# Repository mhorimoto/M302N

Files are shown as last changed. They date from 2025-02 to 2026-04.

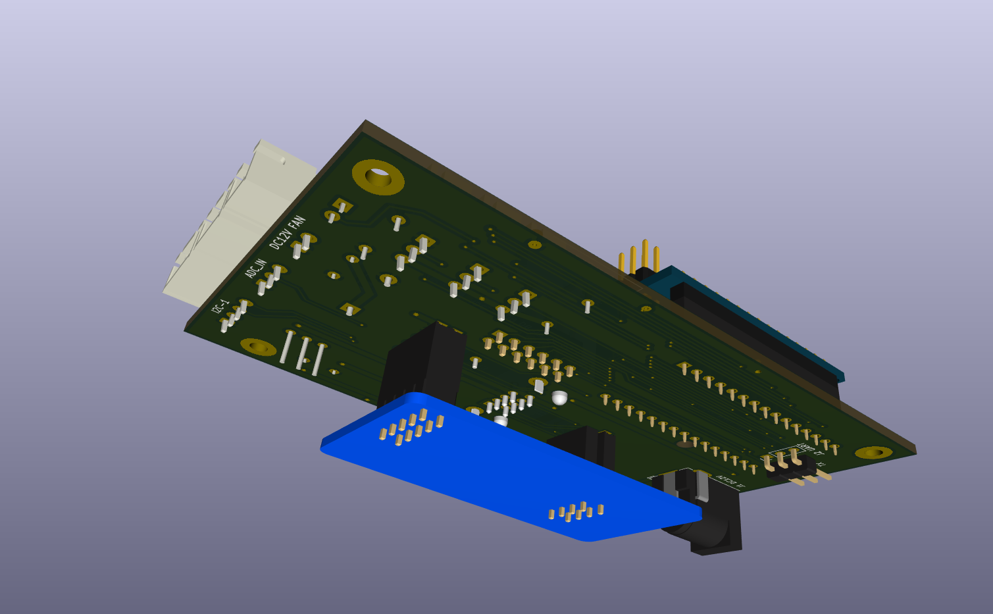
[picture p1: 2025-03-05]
M302N-3D-02.png

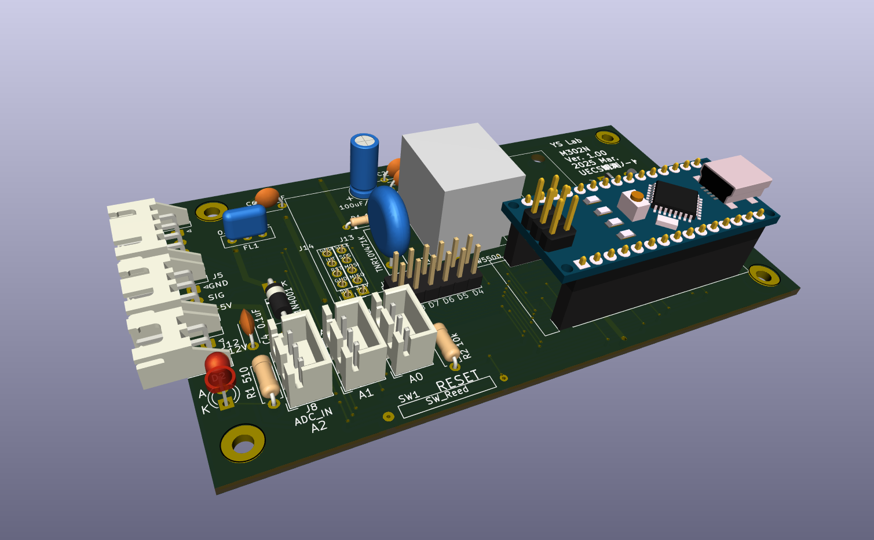
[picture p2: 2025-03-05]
M302N-3D-01.png

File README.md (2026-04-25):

# M302N3

New hardware that improves on the M302K to make it smaller, more dedicated and no-code.

M302Kを改良して小型化、専用化とノーコード化を目指した新しいハードウェア  
M302N2を使用して、
* 気温湿度
* CO2
* 光量子 or 日射量
* 土中水分

を1台で観測可能とする

ここまでが M302N2-ULTRA これからが、M302N3 本当のPoEを採用する

## Main specifications

## パーツリスト

N3のための新規パーツ（現在検討中）

+ RJ-45モジュール Pulse YAGEO J00-0065NL
+ PoE モジュール Silvertel Ag9912-MT 12V出力の工業規格

## 主諸元
+ I2CとADC入力を備えたUECS測定ノード機
+ I/Oは5V
+ 電源電圧はDC12V/1A(Max)
+ M800系のPoEは使えなくなる

## Revision List

### 1.00 初版 (2025/03/09)
### 2.00 
* J1の結線ミスを修正 (Done 2025/05/12)
* J2のUARTはSoftwareSerial対応にして、D0,D1を空けておき、D8,D9をRX,TXに割り当てる。5V Vccの追加。 (Done 2025/05/12)
* J3の対応ピンを変更する。Hardware InterruptのD2,D3を入力端子として扱えるように。D2,3,4,5,6,7 (Done 2025/05/12)
* LED-D2はA0に割り当てる
* J9,J10 の削除 (Done 2025/05/12)
* J11 止め穴を0.1mm大きくする
* SW1はXH-B2Bに変更 (Done 2025/05/12)
* J1へCPUから5Vが逆流しないように1S4を追加 (Done 2025/05/12)
### 3.00

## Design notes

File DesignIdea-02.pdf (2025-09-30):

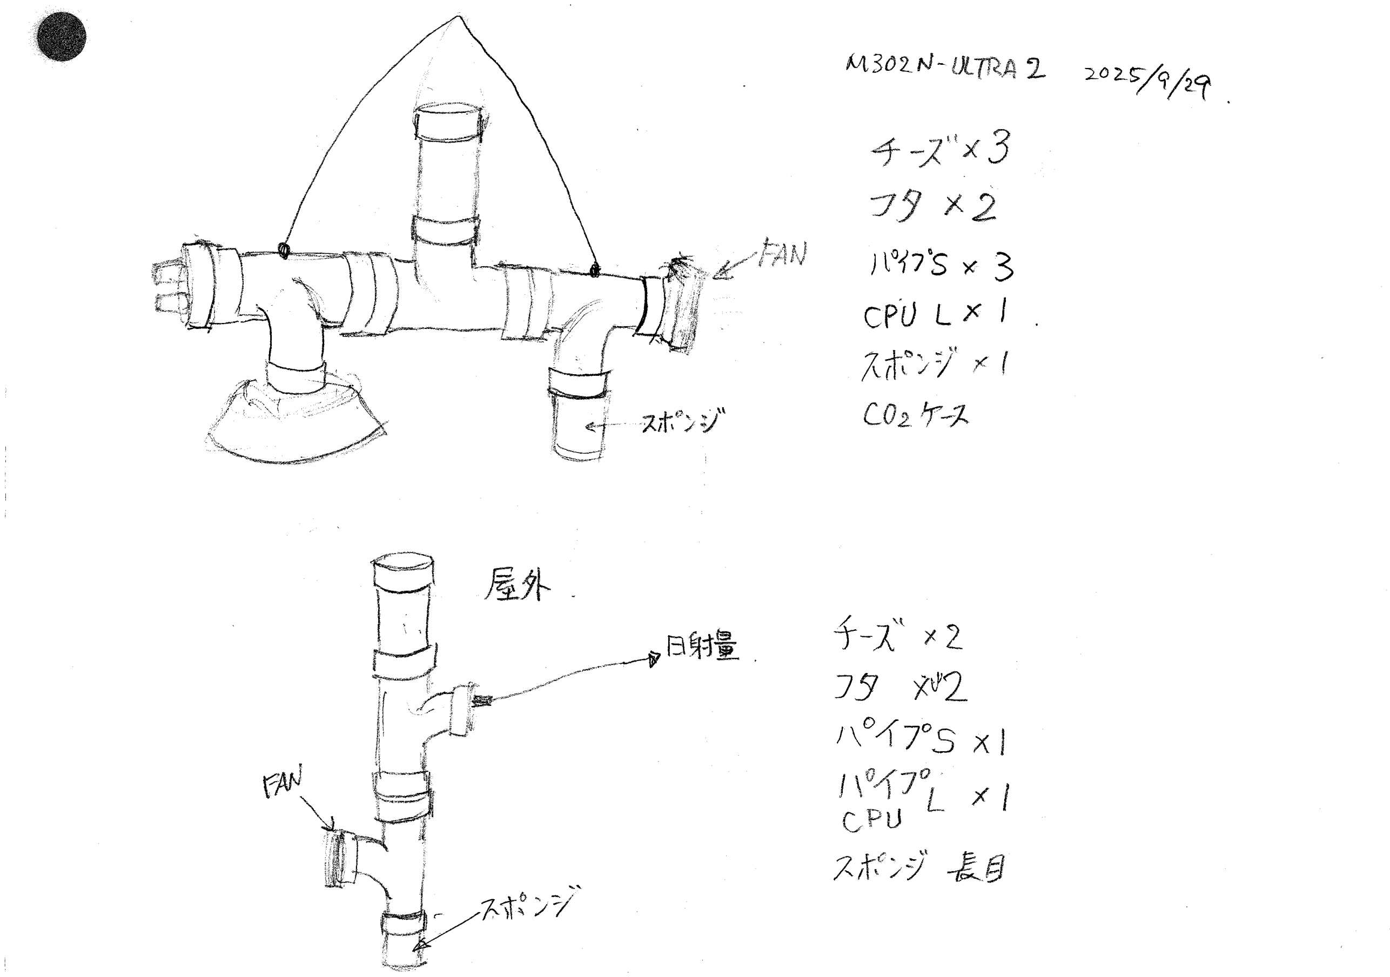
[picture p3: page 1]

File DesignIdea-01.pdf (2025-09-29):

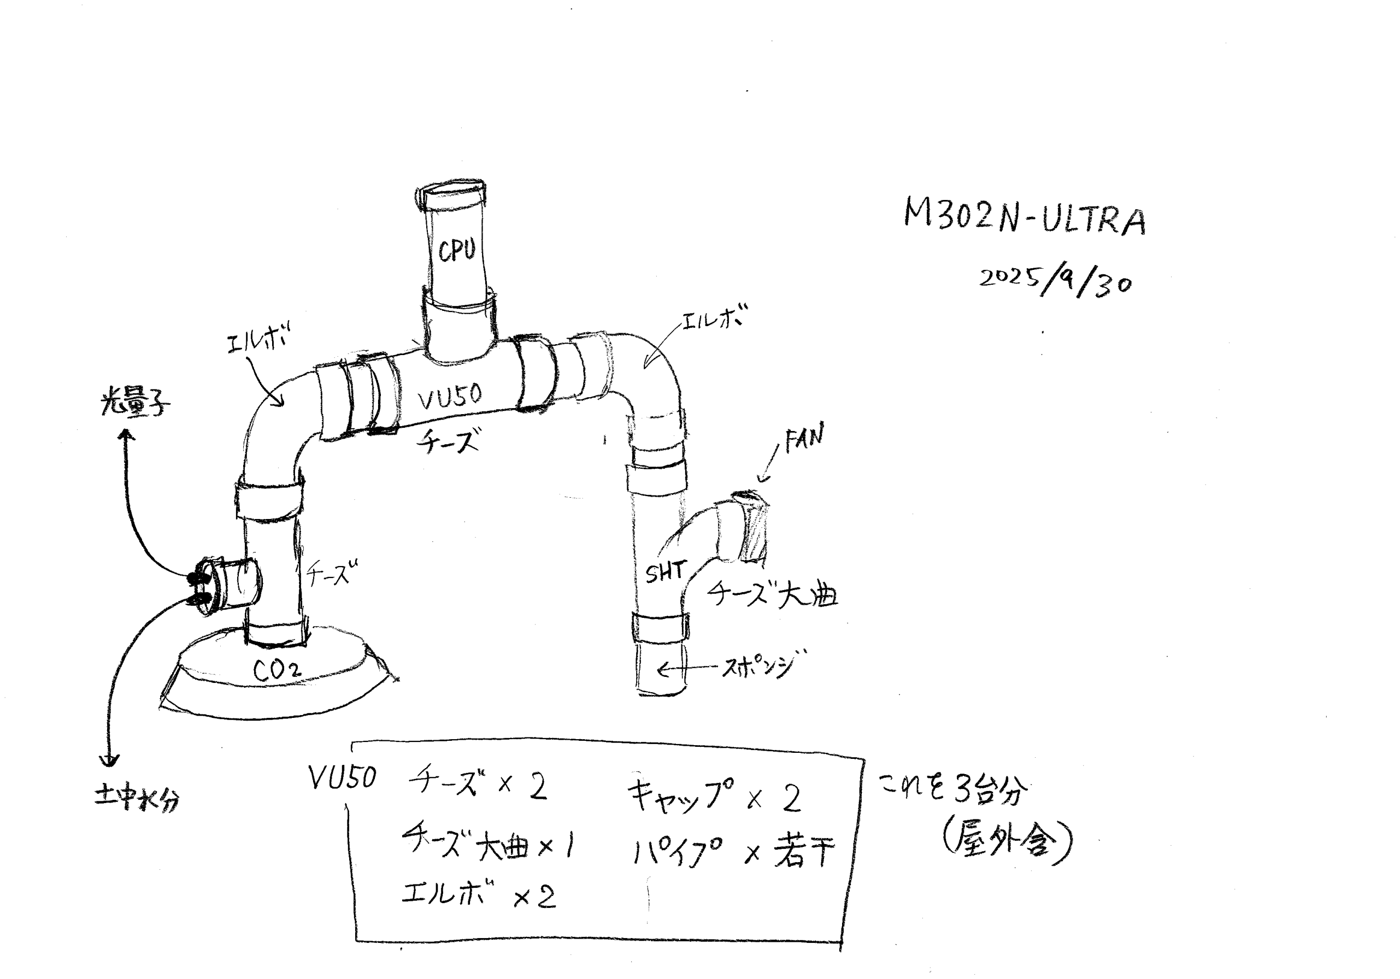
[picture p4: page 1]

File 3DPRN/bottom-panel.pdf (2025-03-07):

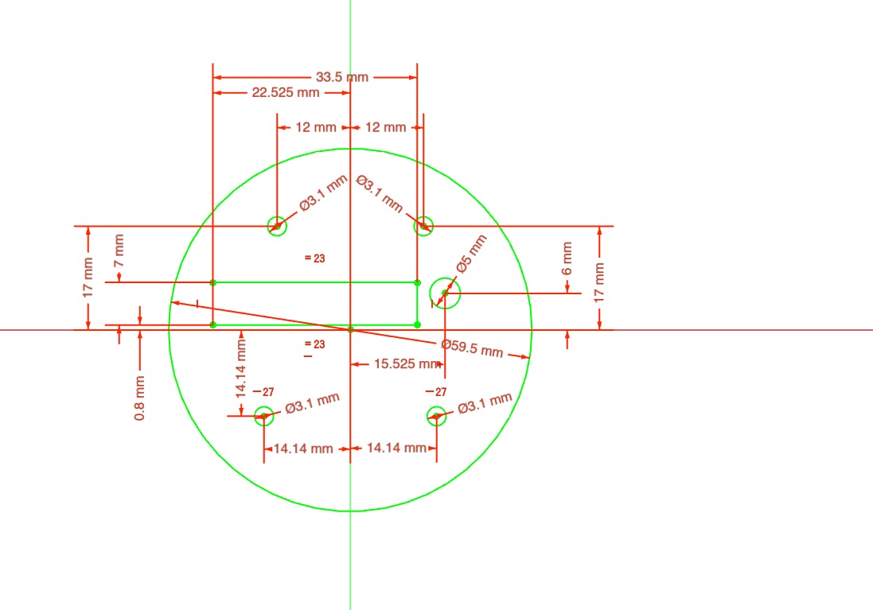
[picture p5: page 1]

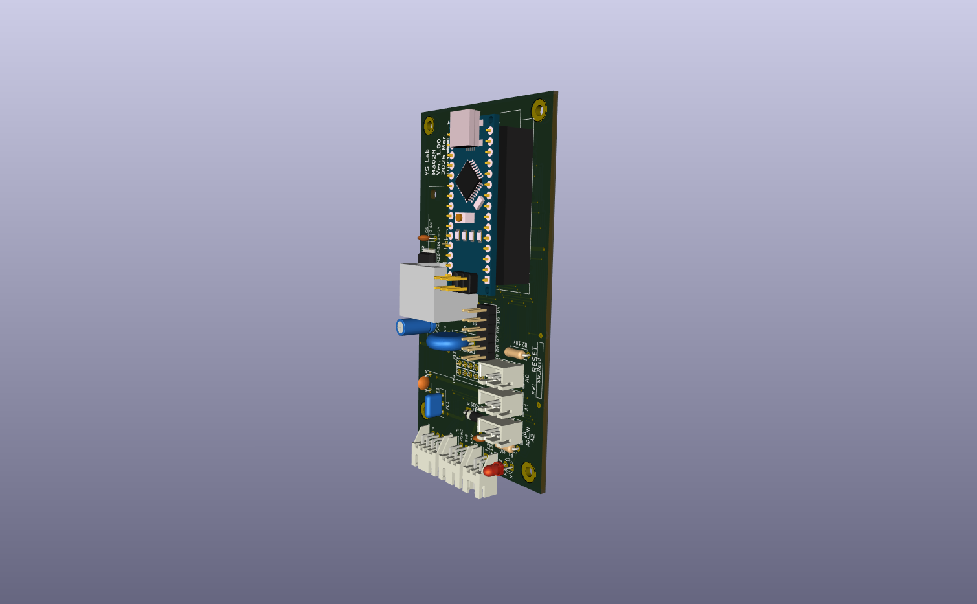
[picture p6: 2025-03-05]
M302N-3D-03.png

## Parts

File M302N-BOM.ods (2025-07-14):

Reference | Value | Datasheet | Footprint | Qty | DNP | 説明
A1 | Arduino_Nano_v3.x | http://www.mouser.com/pdfdocs/Gravitech_Arduino_Nano3_0.pdf | Module:Arduino_Nano | 1 |  | Arduino Nano v3.x
C1 | 100uF/25V | ~ | Capacitor_THT:C_Radial_D5.0mm_H11.0mm_P2.00mm | 1 |  | Polarized capacitor, small symbol
C2,C4,C5 | 0.1uF | ~ | Capacitor_THT:C_Disc_D4.3mm_W1.9mm_P5.00mm | 3 |  | Unpolarized capacitor, small symbol
D1,D4 | 1S4 | ~ | Resistor_THT:R_Axial_DIN0204_L3.6mm_D1.6mm_P5.08mm_Horizontal | 2 |  | Schottky diode
D2 | LED | ~ | LED_THT:LED_D3.0mm | 1 |  | Light emitting diode
D3 | 1N4001 | http://www.vishay.com/docs/88503/1n4001.pdf | Diode_THT:D_DO-41_SOD81_P10.16mm_Horizontal | 1 |  | 50V 1A General Purpose Rectifier Diode, DO-41
F1 | LVR040 | https://html.alldatasheet.jp/html-pdf/346655/MACOM/LVR040/149/1/LVR040.html | Fuse:Fuse_BelFuse_0ZRE0033FF_L11.4mm_W3.8mm | 1 |  | Resettable fuse, polymeric positive temperature coefficient, small symbol
FL1 | 0.1uF DDS1 | http://www.murata.com/~/media/webrenewal/support/library/catalog/products/emc/emifil/c31e.ashx?la=en-gb | HOLLY2:DSS1 | 1
J1 | DC12V | ~ | Connector_BarrelJack:BarrelJack_GCT_DCJ200-10-A_Horizontal | 1 |  | DC Barrel Jack with an internal switch
J2 | UART | ~ | Connector_JST:JST_XH_S4B-XH-A_1x04_P2.50mm_Horizontal | 1 |  | Generic connector, single row, 01x04, script generated (kicad-library-utils/schlib/autogen/connector/)
J3 | extend I/O | ~ | Connector_PinHeader_2.54mm:PinHeader_2x06_P2.54mm_Vertical | 1 |  | Generic connector, double row, 02x06, odd/even pin numbering scheme (row 1 odd numbers, row 2 even numbers), script generated (kicad-library-utils/schlib/autogen/connector/)
J4 | I2C-1 | ~ | Connector_JST:JST_XH_S4B-XH-A_1x04_P2.50mm_Horizontal | 1 |  | Generic connector, single row, 01x04, script generated (kicad-library-utils/schlib/autogen/connector/)
J5,J6 | ADC_IN | ~ | -- ミックスされた値 -- | 2 |  | Generic connector, single row, 01x03, script generated (kicad-library-utils/schlib/autogen/connector/)
J7 | RESET | ~ | Connector_JST:JST_XH_S2B-XH-A_1x02_P2.50mm_Horizontal | 1 |  | Generic connector, single row, 01x02, script generated (kicad-library-utils/schlib/autogen/connector/)
J11 | RJ45 | ~ | HOLLY2:RJ45_Neltron_7810-8P8C | 1 |  | RJ connector, 8P8C (8 positions 8 connected)
J12 | DC12V FAN | ~ | Connector_JST:JST_XH_S2B-XH-A_1x02_P2.50mm_Horizontal | 1 |  | Generic connector, single row, 01x02, script generated (kicad-library-utils/schlib/autogen/connector/)
J13,J14 | Conn_01x05_Socket | ~ | Connector_PinSocket_2.54mm:PinSocket_1x05_P2.54mm_Vertical | 2 |  | Generic connector, single row, 01x05, script generated
J15,J16 | Conn_01x05_Pin | ~ |  | 2 |  | Generic connector, single row, 01x05, script generated
J17 | Conn_01x08_Pin | ~ |  | 1 |  | Generic connector, single row, 01x08, script generated
J18,J19 | Conn_01x04_Socket | ~ | Connector_PinSocket_2.54mm:PinSocket_1x04_P2.54mm_Vertical | 2 |  | Generic connector, single row, 01x04, script generated
R1 | 510 | ~ | Resistor_THT:R_Axial_DIN0207_L6.3mm_D2.5mm_P7.62mm_Horizontal | 1 |  | Resistor, US symbol
R2 | 10k | ~ | Resistor_THT:R_Axial_DIN0207_L6.3mm_D2.5mm_P7.62mm_Horizontal | 1 |  | Resistor, US symbol
R3 | TNR10V471K | ~ | Varistor:RV_Disc_D12mm_W3.9mm_P7.5mm | 1 |  | Variable resistor, US symbol
U1 | W5500 |  | HOLLY2:W5500LARGE | 1
U2 | BP5293-50 | BP5293-50 | footprints:SIP03_BP5293_17X7P2_ROM | 1

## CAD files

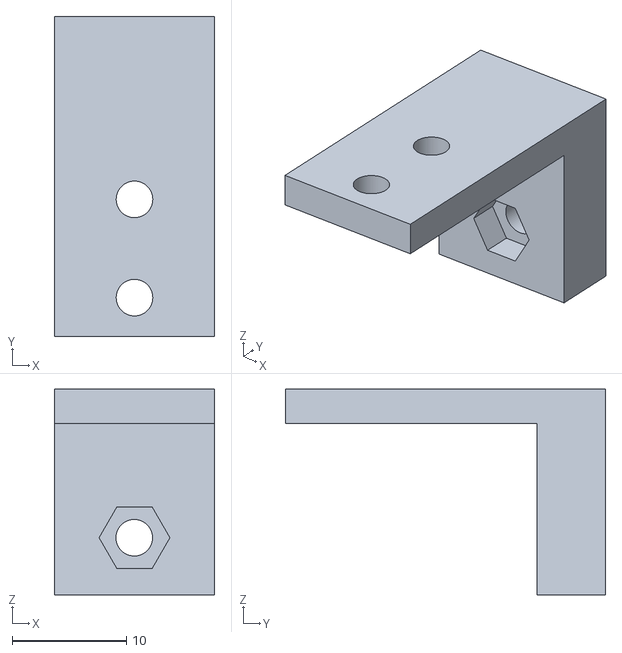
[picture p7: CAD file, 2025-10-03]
3DPRN/Pipe-type/電源ボックス_ネジ.stl
14.0 x 28.0 x 18.0

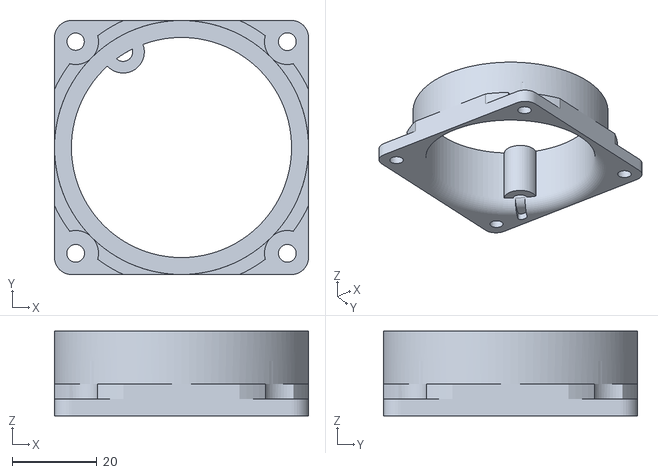
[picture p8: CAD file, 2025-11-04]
3DPRN/ファン・CO2用コネクタ.stl
60.0 x 60.0 x 20.0

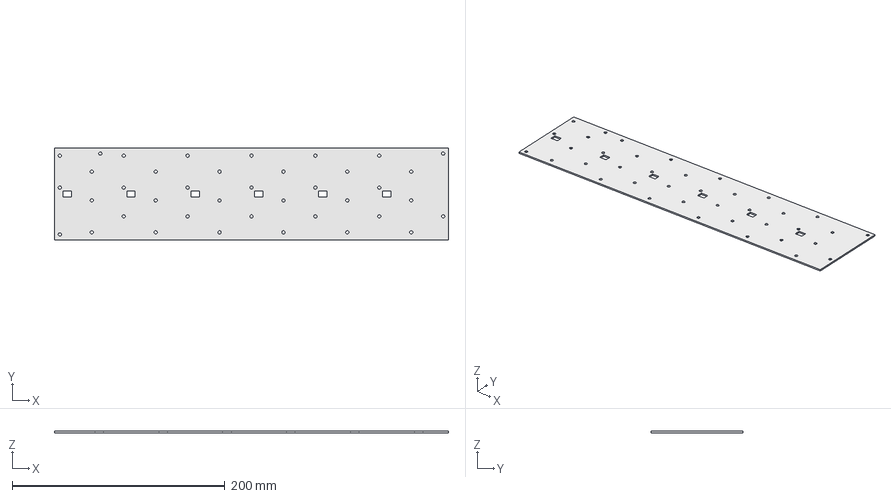
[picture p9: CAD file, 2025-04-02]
3DPRN/NC-PoE-Base.FCStd
370.0 x 86.0 x 1.50 mm

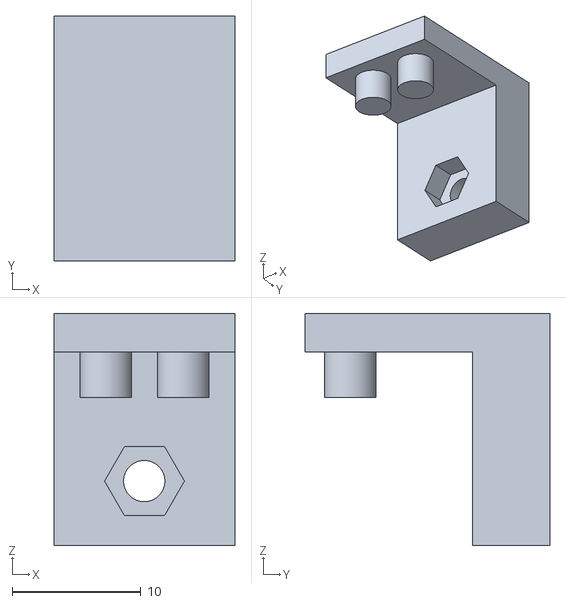
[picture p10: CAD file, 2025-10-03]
3DPRN/Pipe-type/電源ボックス_穴のみ.stl
14.0 x 19.0 x 18.0

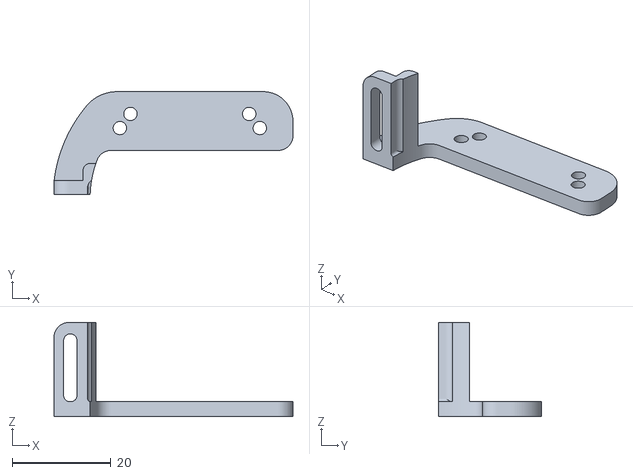
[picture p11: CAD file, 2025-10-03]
3DPRN/Pipe-type/基板サポート下.stl
48.3 x 20.8 x 19.0

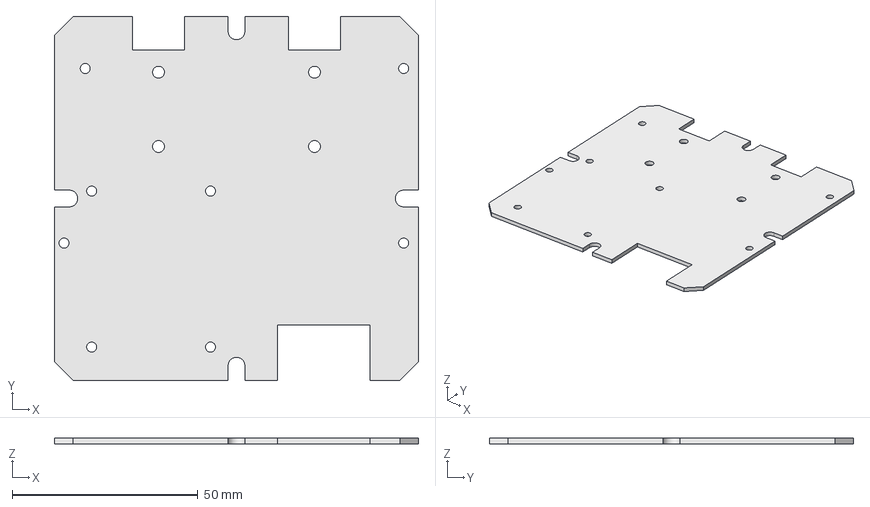
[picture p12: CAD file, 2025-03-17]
3DPRN/SMP1313-M252-4.FCStd
98.0 x 98.0 x 1.50 mm

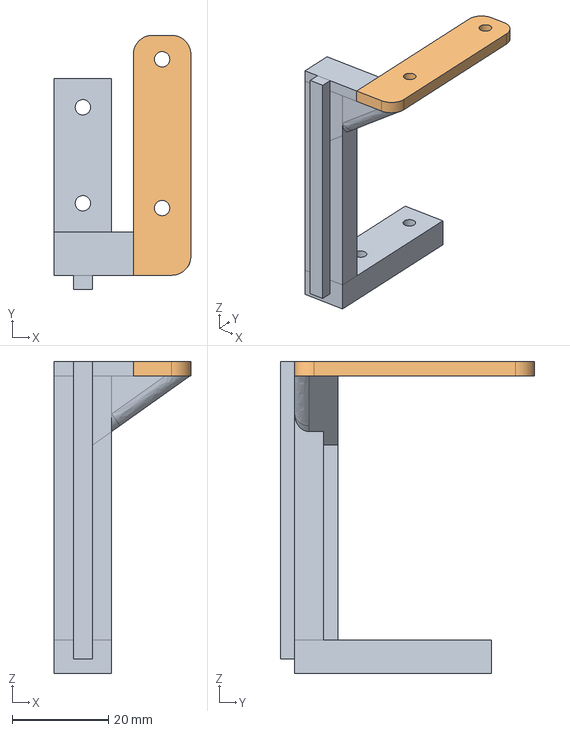
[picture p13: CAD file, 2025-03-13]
3DPRN/LCD-Frame-3L.FCStd
28.5 x 53.0 x 65.0 mm
virtical_bottom
topPanel

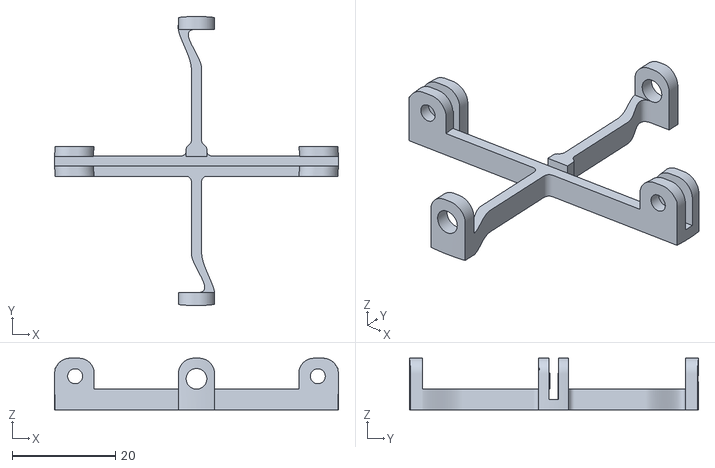
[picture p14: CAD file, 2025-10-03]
3DPRN/Pipe-type/基板サポート上.stl
55.0 x 56.0 x 10.0

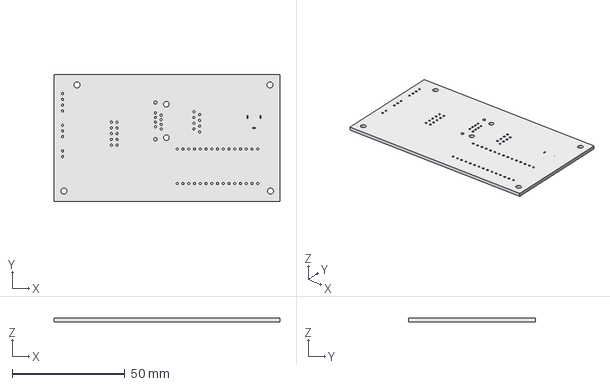
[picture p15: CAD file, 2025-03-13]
3DPRN/PCB-model-Base-56.FCStd
100.0 x 56.0 x 1.60 mm

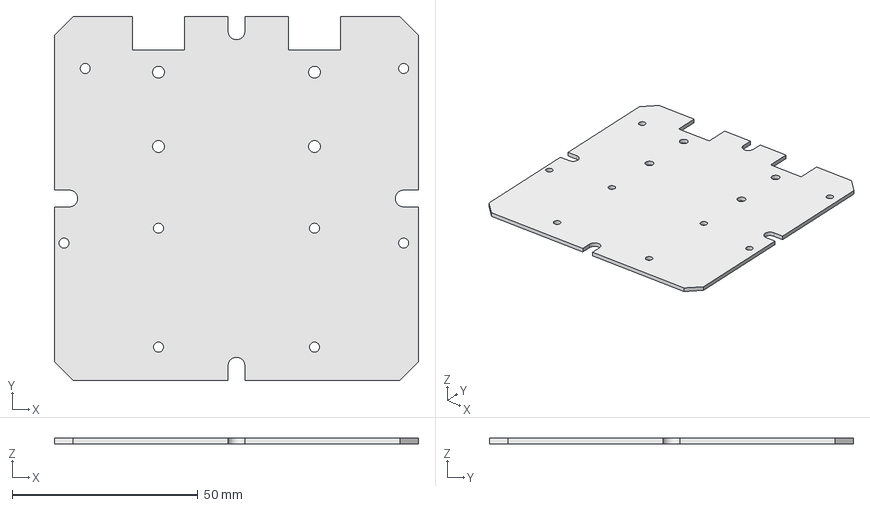
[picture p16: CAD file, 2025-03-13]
3DPRN/SMP1313-M252-3.FCStd
98.0 x 98.0 x 1.50 mm

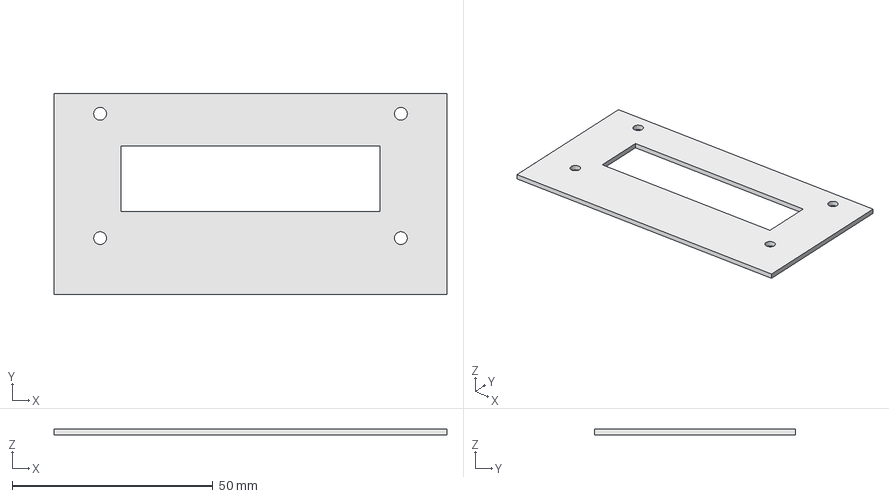
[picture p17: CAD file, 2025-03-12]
3DPRN/LCD-Panel_13mm.FCStd
98.0 x 50.0 x 1.50 mm

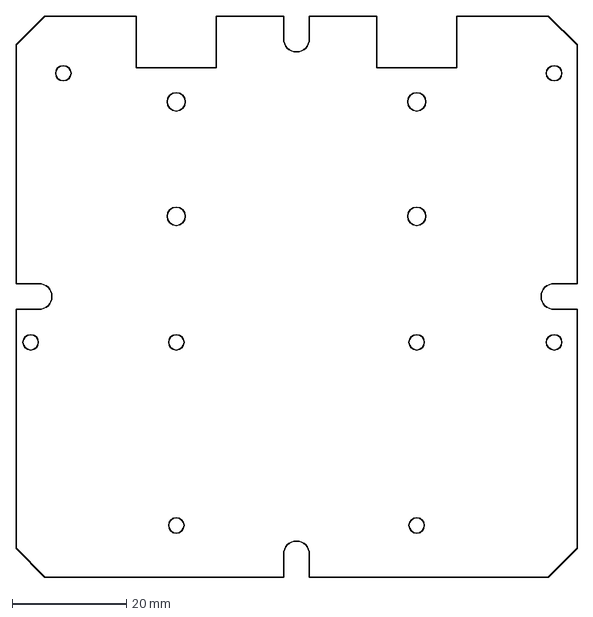
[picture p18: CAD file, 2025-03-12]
3DPRN/SMP1313-M252-2.dxf
98.0 x 98.0 mm

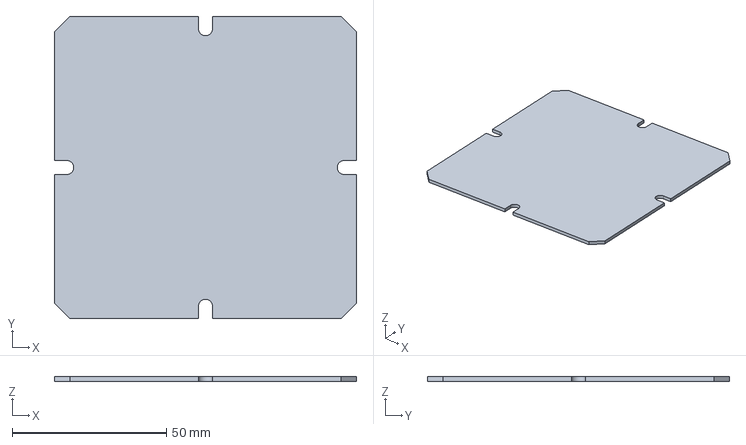
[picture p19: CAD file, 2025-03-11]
3DPRN/SMP1313.FCStd
98.0 x 98.0 x 1.50 mm

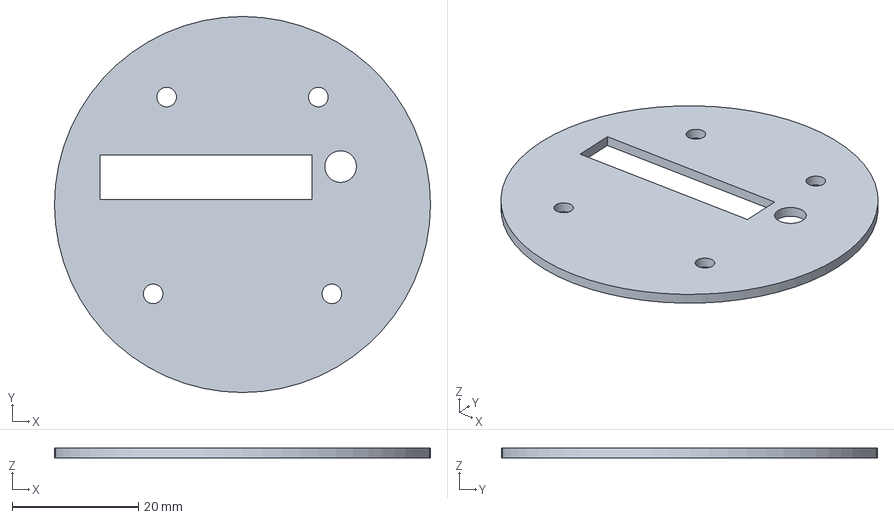
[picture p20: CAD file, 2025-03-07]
3DPRN/bottom-panel.FCStd
59.5 x 59.5 x 1.60 mm

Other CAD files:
3DPRN/Pipe-type/ダクト.stl
3DPRN/LCD-Frame-2R.FCStd
3DPRN/LCD-Panel.FCStd
3DPRN/PCB-model-Base-BodySketch.dxf
3DPRN/LCD-Frame-2R.stl
3DPRN/LCD-Frame-3L.stl
3DPRN/LCD-Panel.dxf
3DPRN/LCD-Panel_13mm.dxf
3DPRN/NC-PoE-Base.dxf
3DPRN/PCB-model-Base-56.dxf
3DPRN/SMP1313-M252-3.dxf
3DPRN/SMP1313-M252-4.dxf
3DPRN/bottom-panel.dxf

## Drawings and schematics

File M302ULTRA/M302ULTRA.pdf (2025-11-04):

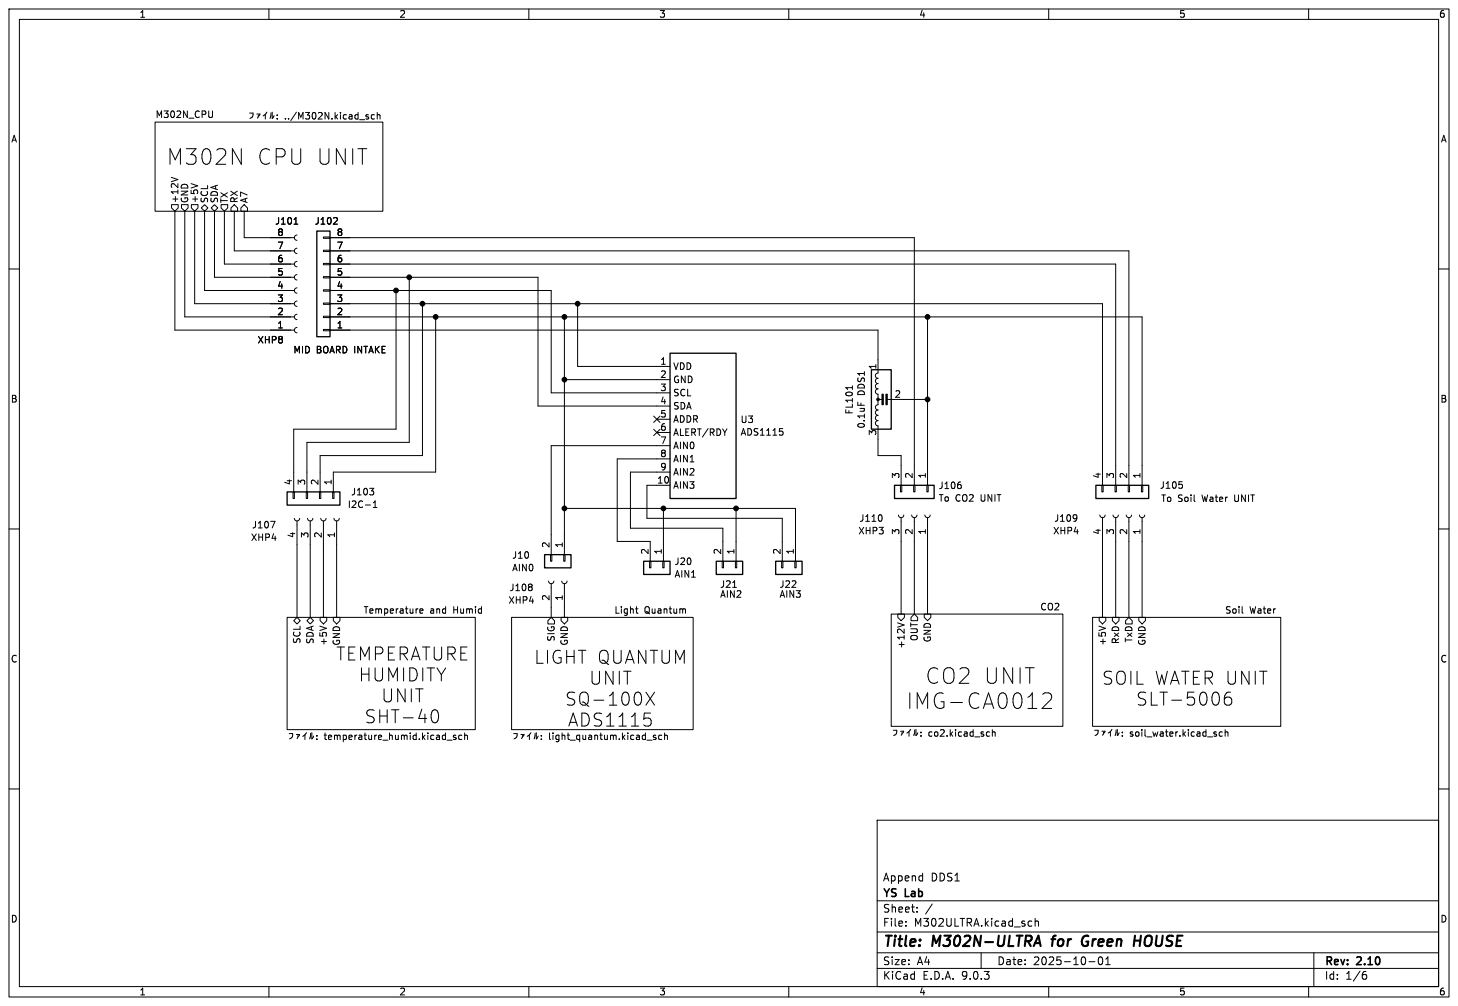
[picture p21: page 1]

J105 To Soil Water UNIT

Soil Water þÿ0Õ0¡0¤0ë: soil_water.kicad_sch GND SIG

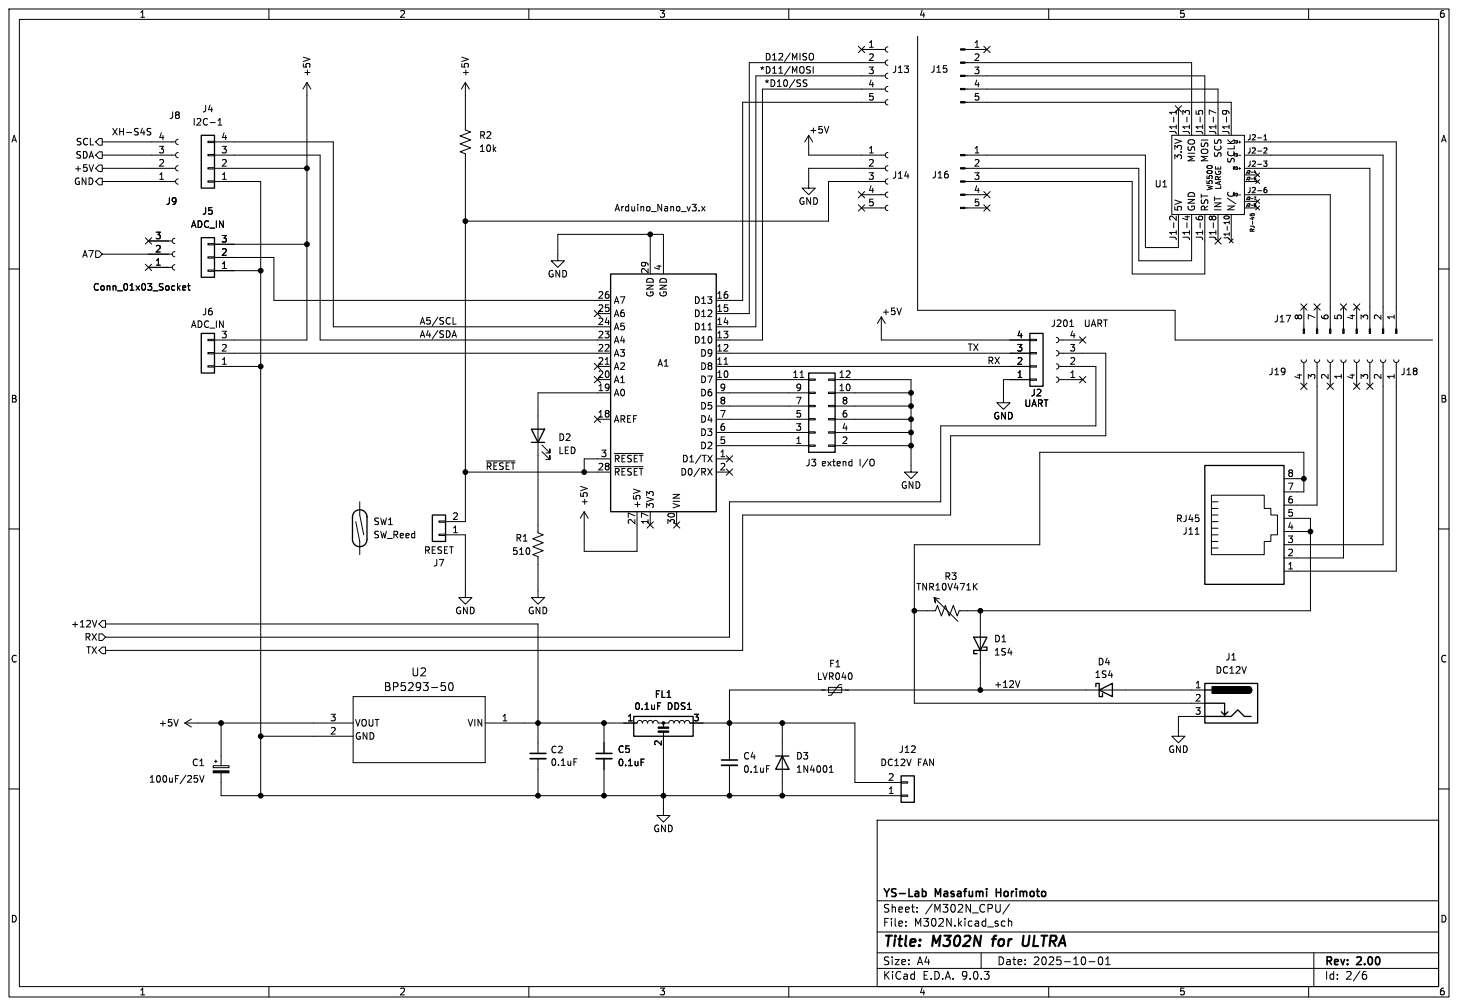
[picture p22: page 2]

LARGE RJ-45 3.3V J1-1 MISO J1-3 MOSI J1-5 SCS J1-7 SCLK J1-9 TD+ J2-1

Id: 2/6 Title: M302N for ULTRA

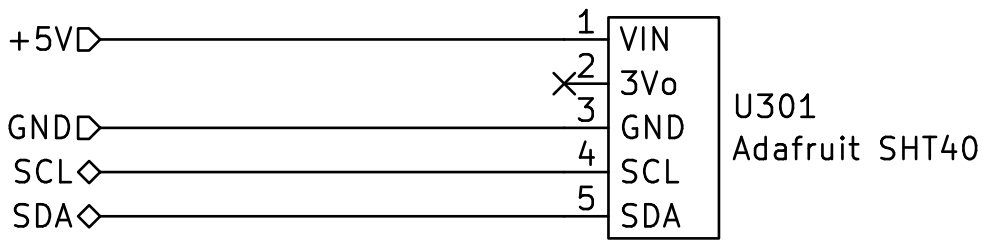
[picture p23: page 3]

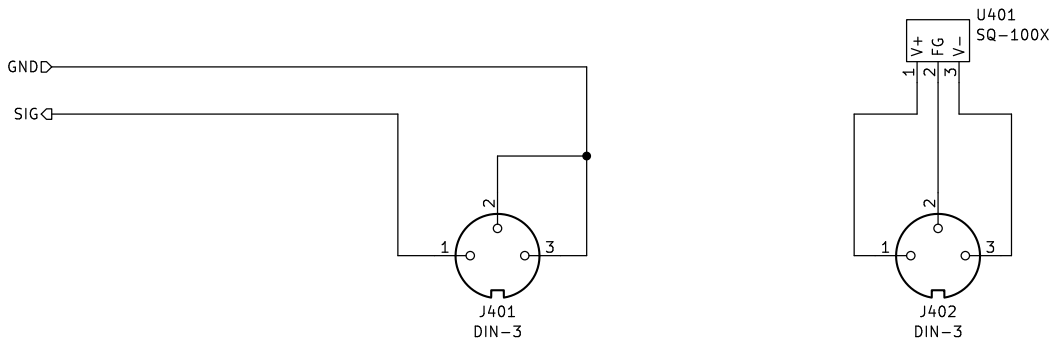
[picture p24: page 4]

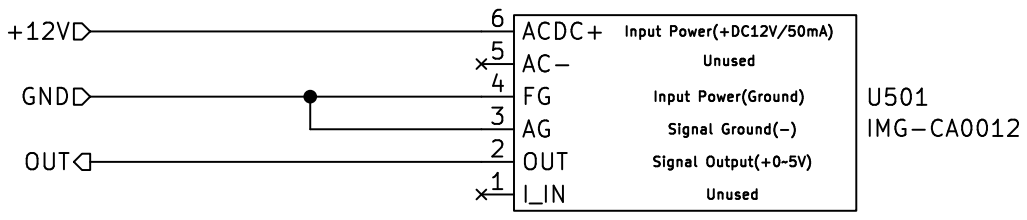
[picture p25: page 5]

Input Power(Ground) Unused

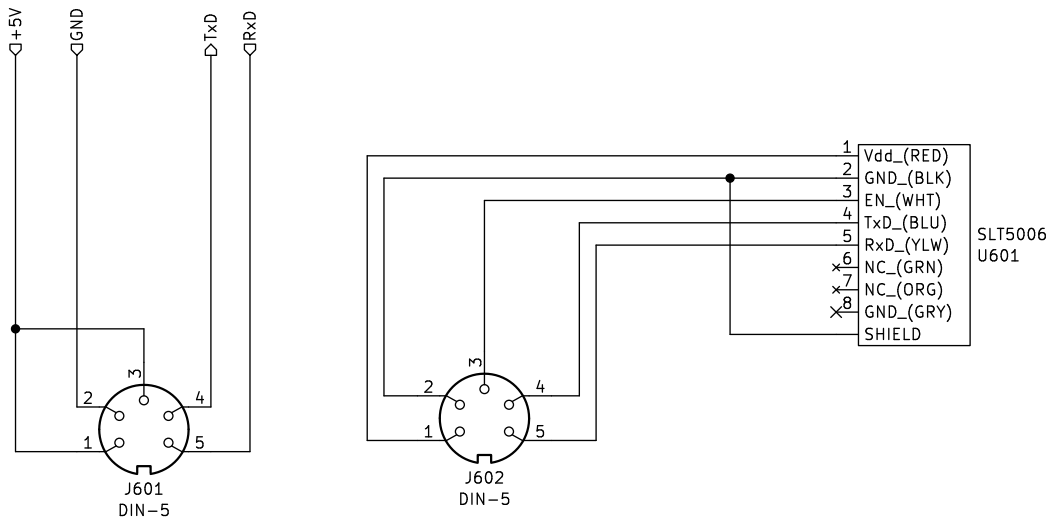
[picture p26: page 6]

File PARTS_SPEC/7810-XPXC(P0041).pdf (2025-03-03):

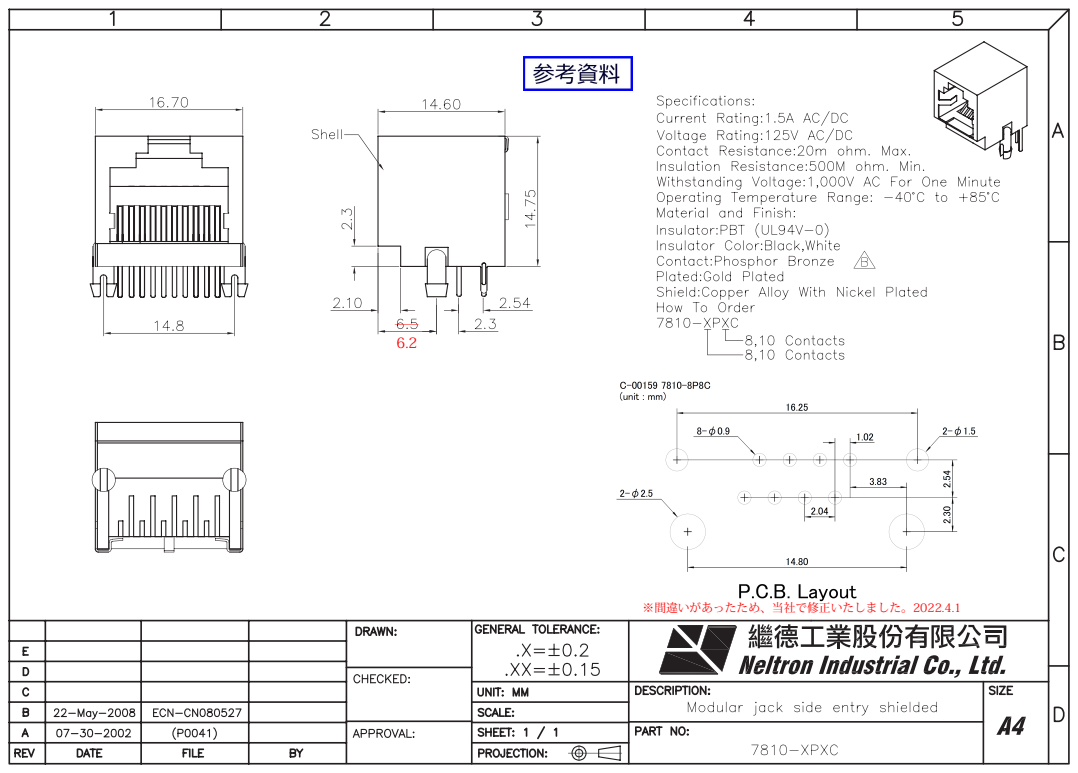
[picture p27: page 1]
※間違いがあったため、当社で修正いたしました。2022.4.1 ──6.2

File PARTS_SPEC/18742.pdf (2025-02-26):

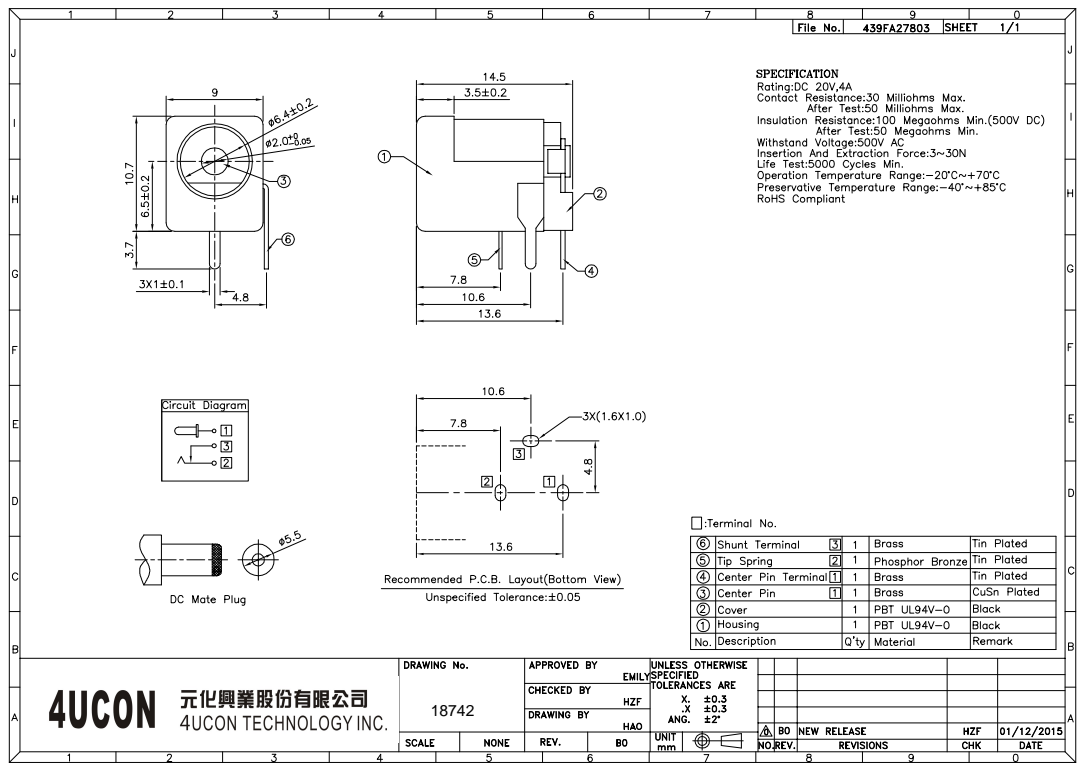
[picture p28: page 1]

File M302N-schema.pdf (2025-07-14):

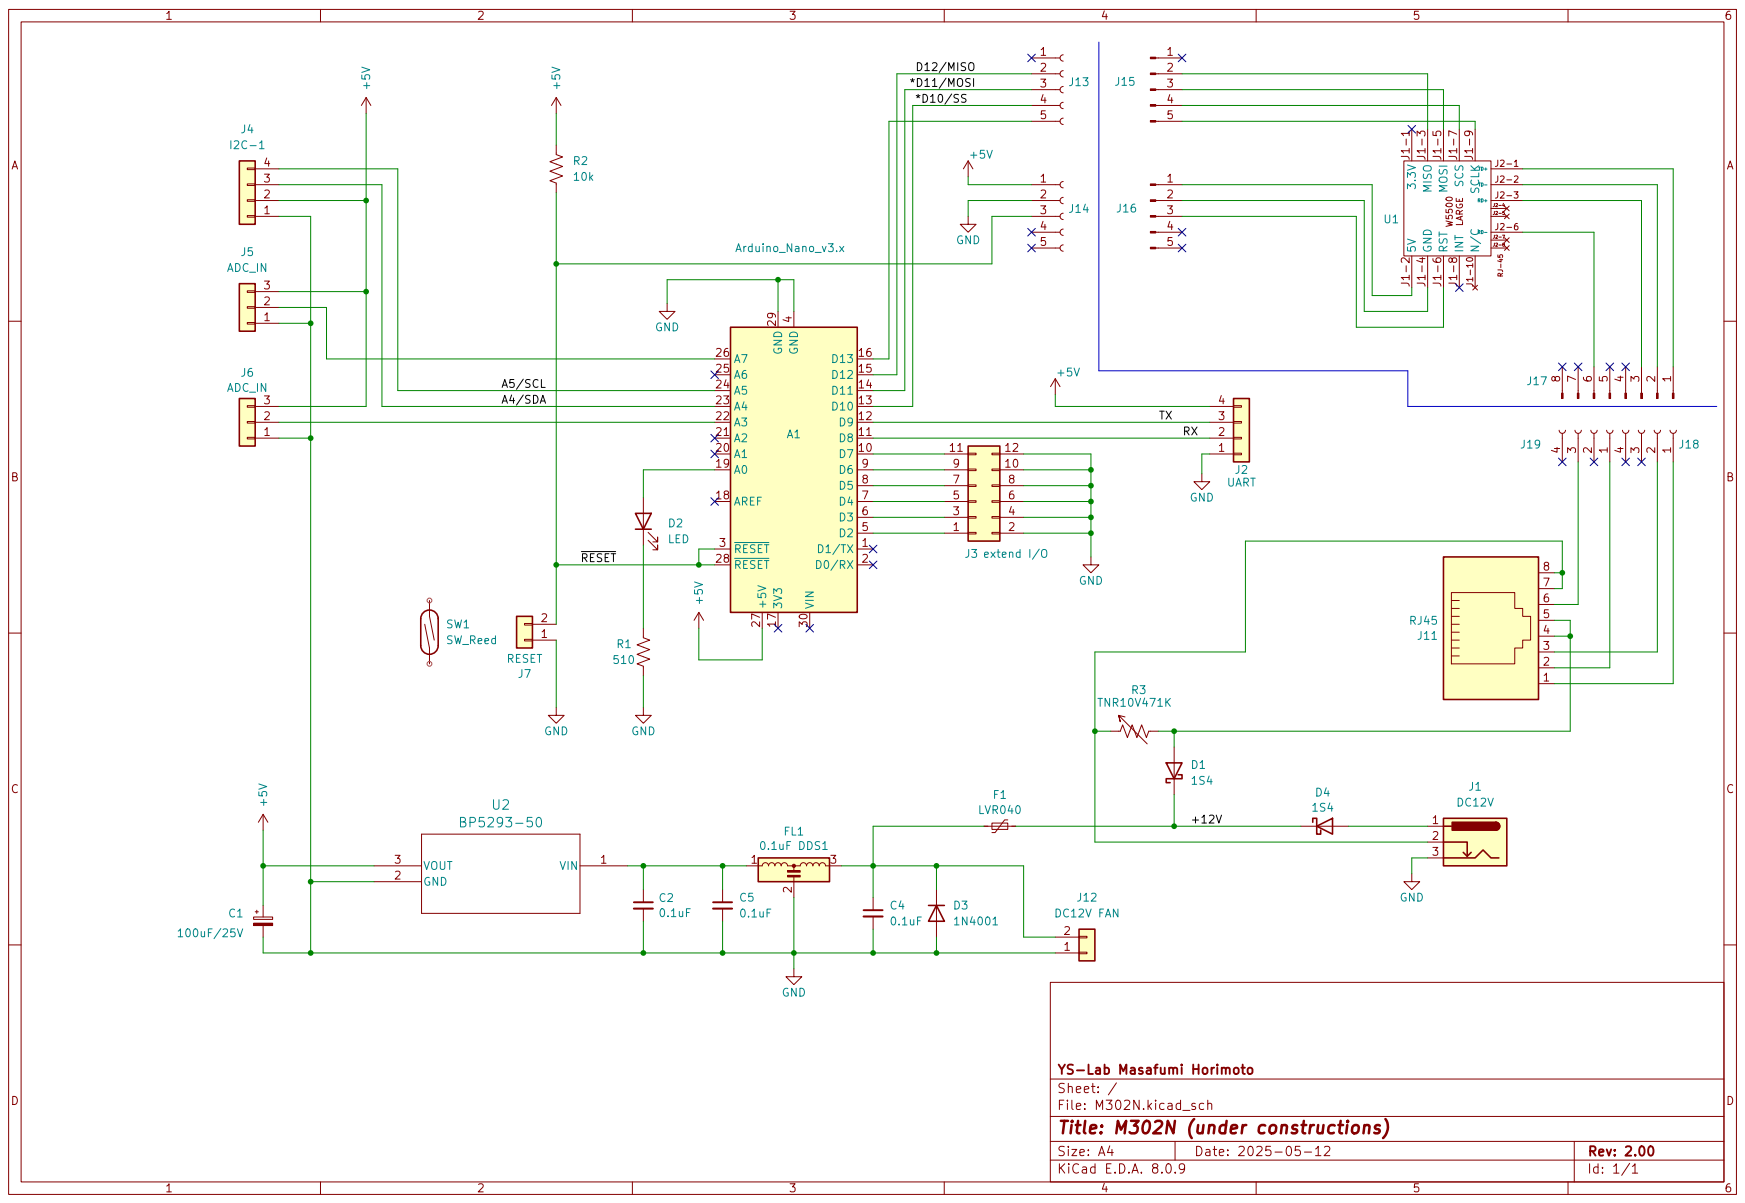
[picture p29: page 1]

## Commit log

2025-02-18 3D data fan fannel
    [fan-fannel.FCStd, fan-fannel.stl]
2025-02-25 W5500新しいシンボルとフットパターン
    [M302N.kicad_sch]
2025-02-26 W5500との接続はソケット
    [M302N.kicad_pcb, M302N.kicad_sch]
2025-02-28 PCB設計途中
    [M302N.kicad_pcb, M302N.kicad_sch]
2025-03-03 PCB設計とRJ45モジュラー
    [M302N.kicad_pcb, M302N.kicad_sch]
2025-03-04 PCB設計中
    [M302N.kicad_pcb, M302N.kicad_sch]
2025-03-04 PCB継続
    [M302N.kicad_pcb, M302N.kicad_sch]
2025-03-05 PCB基本完成・文字入れなど未完
    [M302N.kicad_pcb]
2025-03-05 PCBほぼ完成
    [M302N.kicad_pcb]
2025-03-06 3D機構データ
    [PCB-model-Base-BodySketch.dxf, PCB-model-Base.FCStd, bottom-panel.FCStd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]
2025-03-07 3Dデータ更新とRJ45コネクタの取り付け位置微妙に変更
    [M302N.kicad_pcb, bottom-panel.FCStd, fan-fannel.FCStd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]
2025-03-07 もうすぐ完成
    [M302N.kicad_pcb, M302N.kicad_sch]
2025-03-09 PCB発注
    [M302N-BOM.ods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]
2025-03-11 機構部品を設計
    [LCD-Frame.FCStd, LCD-Frame.stl, LCD-Panel.FCStd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]
2025-03-12 機構部品製作
    [LCD-Frame-2.FCStd, LCD-Frame-2L.FCStd, LCD-Frame-2L.stl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]
2025-03-13 機構部品ほぼ合わせ終わり
    [LCD-Frame-2.FCStd, LCD-Frame-2L.FCStd, LCD-Frame-2L.stl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]
2025-03-17 底板のデザイン変更
    [SMP1313-M252-4.FCStd, SMP1313-M252-4.dxf]
2025-04-02 NC-PoEアクリル基板図面
    [NC-PoE-Base.FCStd, NC-PoE-Base.dxf]
2025-04-02 V2.00はじめ
    [M302N.kicad_sch]
2025-05-12 回路図上の変更は完了。PCB部品の選定に入る所。
    [M302N.kicad_pcb, M302N.kicad_sch]
2025-06-02 v2.00 PCB変更とスイッチングレギュレータ採用検討
    [M302N.kicad_pcb, M302N.kicad_sch]
2025-06-03 DCDC converter
    [M302N.kicad_sch]
2025-06-03 大胆な変更
    [M302N.kicad_pcb, M302N.kicad_sch]
2025-06-03 v2.00 ほぼ完成？
    [M302N.kicad_pcb]
2025-06-04 PCBのdesign rule check中
    [M302N.kicad_pcb]
2025-07-14 更新し直し
    [M302N-BOM.ods]
2025-08-29 KiCAD 9.0
    [M302N.kicad_pcb, M302N.kicad_sch]
2025-09-21 センサー類をシンボル化
2025-09-27 Soilを編集中
    [M302N.kicad_sch, M302ULTRA.kicad_sch, co2.kicad_sch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]
2025-09-28 ULTRA初版・まだタイトルなし
    [M302ULTRA.kicad_sch, light_quantum.kicad_sch, soil_water.kicad_sch]
2025-09-29 外観デザインスケッチを追加
    [M302ULTRA.kicad_sch, soil_water.kicad_sch]
2025-09-30 アイディアスケッチ追加
2025-10-01 ULTRA ver 1.00
    [M302N.kicad_sch, M302ULTRA.kicad_sch, co2.kicad_sch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]
2025-10-01 ULTRA ver 2.00
    [M302ULTRA.kicad_sch, light_quantum.kicad_sch]
2025-10-01 Ver 2.10 Append DDS
    [M302ULTRA.kicad_sch]
2025-10-03 パイプ実装のための3Dプリント素材追加
    [ダクト.stl, 基板サポート上.stl, 基板サポート下.stl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]
2026-04-25 PoE部品の選定など
